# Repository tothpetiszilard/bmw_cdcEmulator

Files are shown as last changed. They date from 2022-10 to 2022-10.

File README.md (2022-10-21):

BMW (E46 and E39) CDC (cd changer) emulator project

- Emulates a CD changer node on the IBUS network
- Controls and reads status of KRC 86B V4.0 bluetooth module (onboard)
- Controls a dfPlayer mini USB and microSD card music player module (onboard)
- Receives multifuction steering wheel commands
- Receives commands and status from the original radio
- Supports some configuration options which can be set using the original radio interface

HW design done in EAGLE
SW is done in MPLABX using its MCC code generator

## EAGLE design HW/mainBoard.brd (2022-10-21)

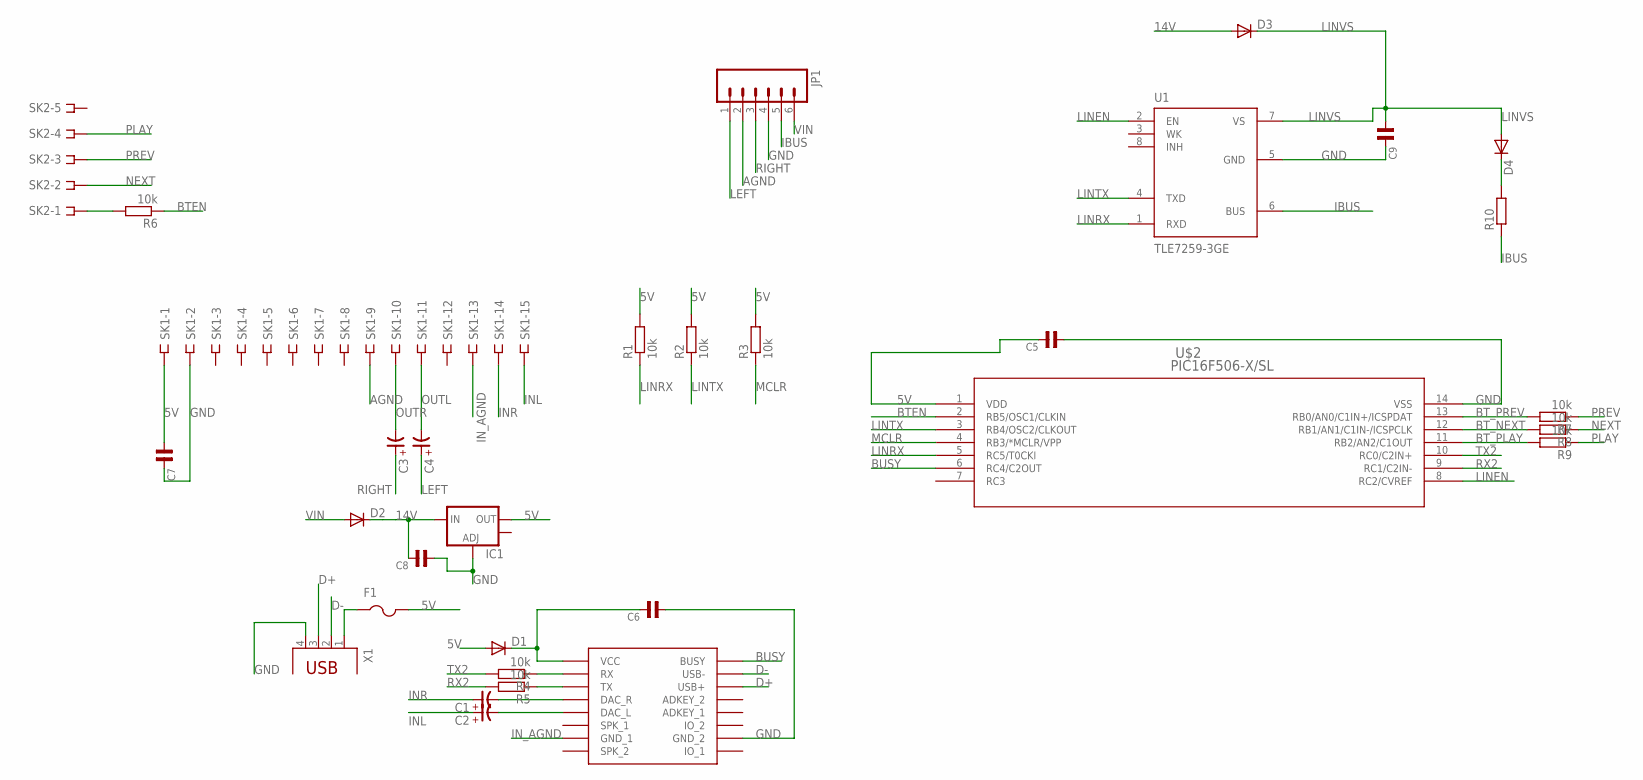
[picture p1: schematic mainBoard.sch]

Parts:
C1, C2, C3, C4: CP-3258-TE-B; 3528-TE-B
C5, C6, C7, C9: C0603; 0603
C8: C1206; 1206
D1, D2: DIODESMA-ALT; SMA-DIODE_ALT
D3, D4: DIODE-SOD80C; SOD80C
F1: PTCFUSE-1812; 1812
IC1: V_REG_LM1117SOT223; SOT223
JP1: M06LONGPADS; 1X06_LONGPADS
R1, R2, R3, R4, R5, R6, R7, R8, R9: 10k; R0603
R10: R-EU_R0603; R0603
SK1: DF3-15S; DF3S-15
SK2: DF3-05S; DF3S-05
U1: TLE7259-3GE; SOIC127P600X175-8N-3
U$1: DFPLAYER
U$2: PIC16F506-X/SL; SOIC14-N_MC
X1: PN87520

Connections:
5V: C5.2, C7.1, D1.A, F1.2, IC1.2 (OUT), R1.2, R2.2, R3.2, SK1.1, U$2.1 (VDD)
14V: C8.2, D2.C, D3.A, IC1.3 (IN)
AGND: JP1.2, SK1.9
BTEN: R6.1, U$2.2 (RB5/OSC1/CLKIN)
BT_NEXT: R8.2, U$2.12 (RB1/AN1/C1IN-/ICSPCLK)
BT_PLAY: R9.2, U$2.11 (RB2/AN2/C1OUT)
BT_PREV: R7.2, U$2.13 (RB0/AN0/C1IN+/ICSPDAT)
BUSY: U$1.BUSY, U$2.6 (RC4/C2OUT)
D+: U$1.USB+, X1.3
D-: U$1.USB-, X1.2
GND: C5.1, C6.1, C7.2, C8.1, C9.2, IC1.1 (ADJ), JP1.4, SK1.2, U1.5 (GND), U$1.GND_2, U$2.14 (VSS), X1.4
IBUS: JP1.5, R10.1, U1.6 (BUS)
INL: C2.+, SK1.15
INR: C1.+, SK1.14
IN_AGND: SK1.13, U$1.GND_1
LEFT: C4.+, JP1.1
LINEN: U1.2 (EN), U$2.8 (RC2/CVREF)
LINRX: R1.1, U1.1 (RXD), U$2.5 (RC5/T0CKI)
LINTX: R2.1, U1.4 (TXD), U$2.3 (RB4/OSC2/CLKOUT)
LINVS: C9.1, D3.C, D4.A, U1.7 (VS)
MCLR: R3.1, U$2.4 (RB3/*MCLR/VPP)
unnamed: C2.-, U$1.DAC_L
unnamed: C1.-, U$1.DAC_R
unnamed: C6.2, D1.C, U$1.VCC
unnamed: R4.1, U$1.RX
unnamed: R5.1, U$1.TX
unnamed: F1.1, X1.1
unnamed: D4.C, R10.2
unnamed: R6.2, SK2.1
NEXT: R8.1, SK2.2
OUTL: C4.-, SK1.11
OUTR: C3.-, SK1.10
PLAY: R9.1, SK2.4
PREV: R7.1, SK2.3
RIGHT: C3.+, JP1.3
RX2: R5.2, U$2.9 (RC1/C2IN-)
TX2: R4.2, U$2.10 (RC0/C2IN+)
VIN: D2.A, JP1.6

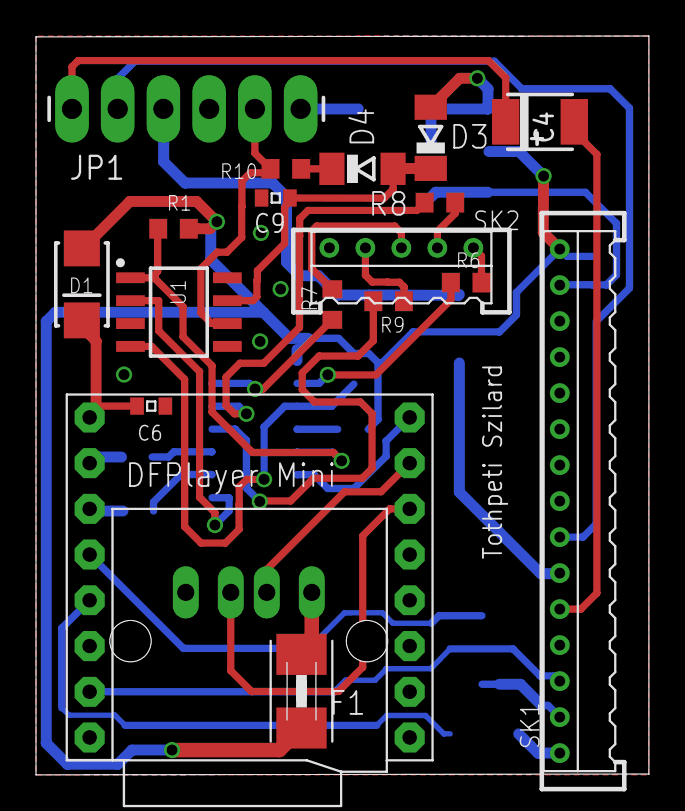
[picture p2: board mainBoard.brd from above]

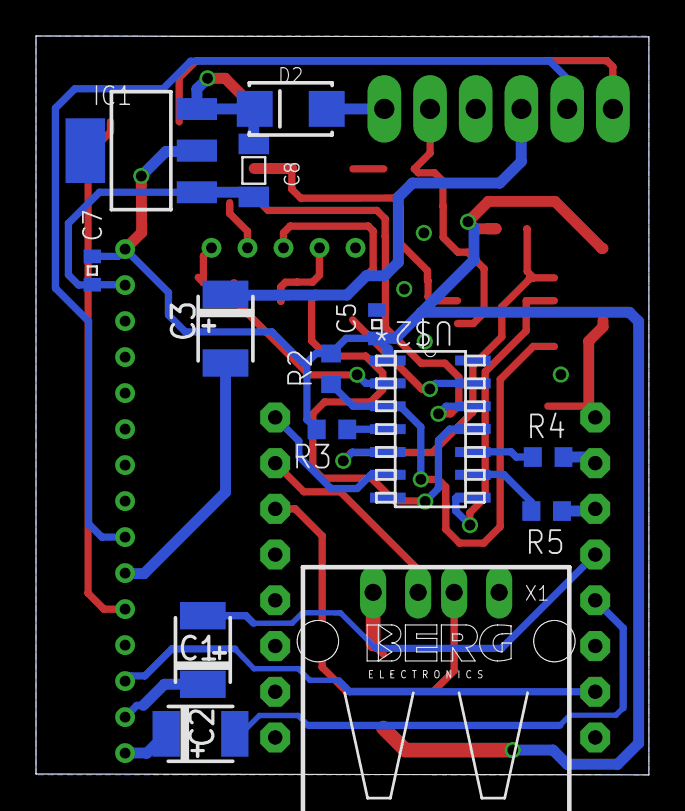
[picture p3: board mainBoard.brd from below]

Board: 2 copper layers, 34.0 x 41.0 mm, 32 parts (14 on the bottom side), 38 nets.

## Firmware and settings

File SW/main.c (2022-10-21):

/**
  Generated Main Source File

  Company:
    Microchip Technology Inc.

  File Name:
    main.c

  Summary:
    This is the main file generated using PIC10 / PIC12 / PIC16 / PIC18 MCUs

  Description:
    This header file provides implementations for driver APIs for all modules selected in the GUI.
    Generation Information :
        Product Revision  :  PIC10 / PIC12 / PIC16 / PIC18 MCUs - 1.65.2
        Device            :  PIC16F18324
        Driver Version    :  2.00
*/

/*
    (c) 2018 Microchip Technology Inc. and its subsidiaries. 
    
    Subject to your compliance with these terms, you may use Microchip software and any 
    derivatives exclusively with Microchip products. It is your responsibility to comply with third party 
    license terms applicable to your use of third party software (including open source software) that 
    may accompany Microchip software.
    
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
    IN NO EVENT WILL MICROCHIP BE LIABLE FOR ANY INDIRECT, SPECIAL, PUNITIVE, 
    INCIDENTAL OR CONSEQUENTIAL LOSS, DAMAGE, COST OR EXPENSE OF ANY KIND 
    WHATSOEVER RELATED TO THE SOFTWARE, HOWEVER CAUSED, EVEN IF MICROCHIP 
    HAS BEEN ADVISED OF THE POSSIBILITY OR THE DAMAGES ARE FORESEEABLE. TO 
    THE FULLEST EXTENT ALLOWED BY LAW, MICROCHIP'S TOTAL LIABILITY ON ALL 
    CLAIMS IN ANY WAY RELATED TO THIS SOFTWARE WILL NOT EXCEED THE AMOUNT 
    OF FEES, IF ANY, THAT YOU HAVE PAID DIRECTLY TO MICROCHIP FOR THIS 
    SOFTWARE.
*/

#include "mcc_generated_files/mcc.h"
#include "BMW_IBUS/IBUS.h"
#include "SysTick/SysTick.h"
#include "BMW_CDC/CDC.h"
/*
                         Main application
 */


void main(void)
{
    // initialize the device
    SYSTEM_Initialize();

    // When using interrupts, you need to set the Global and Peripheral Interrupt Enable bits
    // Use the following macros to:
    // Enable the Global Interrupts
    INTERRUPT_GlobalInterruptEnable();

    // Enable the Peripheral Interrupts
    INTERRUPT_PeripheralInterruptEnable();

    // Disable the Global Interrupts
    //INTERRUPT_GlobalInterruptDisable();

    // Disable the Peripheral Interrupts
    //INTERRUPT_PeripheralInterruptDisable();

    SysTick_Init();
    
    IBUS_Init();

    CDC_Init();    
    while (1)
    {
        // Add your application code
        IBUS_Cyclic();
        CDC_Cyclic();
    }
}
/**
 End of File
*/
    

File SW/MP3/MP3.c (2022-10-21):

#include "MP3.h"
#include "MP3_Cfg.h"

typedef enum _MP3_SrcType_ten
{
    SRC_NOMEDIA = 0u,
    SRC_USB = 1u,
    SRC_SDCARD = 2u
    
}MP3_SrcType_ten;

typedef struct _MP3_ToDoType_tst
{
    uint8_t init_u1 :1;
    uint8_t changeMedia_u1 :1;
    uint8_t getFilesCnt_u1 :1;
    uint8_t start_u1 :1;
    uint8_t pause_u1 :1;
    uint8_t changeTrack_u1 :1;
    uint8_t getTrack_u1 :1;
    uint8_t readNvm_u1 :1;
    uint8_t stop_u1 :1;
}MP3_ToDoType_tst;

static MP3_SrcType_ten currentSrc_en = SRC_NOMEDIA;
static MP3_ToDoType_tst MP3_toDo_st;
static uint8_t MP3_rxBuffer_au8[MP3_RXBUFFER_SIZE];
static uint8_t frameReceived_u8 = 0u;
static uint8_t MP3_txBuffer_au8[MP3_TXBUFFER_SIZE];
static uint16_t currTrack_u16 = 1;
static uint16_t specifiedTrack_u16 = 1u;
static uint16_t maxTrack_u16 = 1;

static uint8_t MP3_MaxTrackInFolder_u8 = 99u;

static void MP3_ProcessFrame(void);
static void MP3_SendCommand(uint8_t cmd_u8, uint8_t para1_u8, uint8_t para2_u8);
static void MP3_Receive(void);
static void MP3_Transmit(void);
static inline void MP3_DecodeRx(void);

void MP3_Init(void)
{
    MP3_UART_INIT();
    frameReceived_u8 = 0u;
    
    MP3_toDo_st.init_u1 = 1u;
    MP3_toDo_st.readNvm_u1 = 1u;
    
}

void MP3_Cyclic(void)
{
    if (0 < frameReceived_u8)
    {
        MP3_ProcessFrame();
    }
    MP3_Receive();
    MP3_Transmit();

}

void MP3_WakeUp(void)
{
   MP3_toDo_st.start_u1 = 1u;
   MP3_toDo_st.getTrack_u1 = 1u;
}

void MP3_SelectTrack(uint8_t folder_u8,uint8_t track_u8)
{
    if (1u < folder_u8)
    {
        specifiedTrack_u16 = ((uint16_t)(folder_u8-1u) * (MP3_MaxTrackInFolder_u8)) + (track_u8);
    }
    else
    {
        specifiedTrack_u16 = (uint16_t)(track_u8);
    }
    
    if (currTrack_u16 != specifiedTrack_u16)
    {
        /* Specify track */
        MP3_toDo_st.changeTrack_u1 = 1u;
    }
    else
    {
        MP3_toDo_st.start_u1 = 1u;
    }
    
}

void MP3_SaveTrack(void)
{
    if (SRC_USB == currentSrc_en)
    {
        MP3_NVM_WRITE(0x1000u | currTrack_u16);
    }
    else
    {
        MP3_NVM_WRITE(currTrack_u16);
    }
}

void MP3_SetMaxTracksPerFolder(uint8_t newValue_u8)
{
    MP3_MaxTrackInFolder_u8 = newValue_u8;
    MP3_NVM_WRITECFG(newValue_u8);
}

uint8_t MP3_GetMaxTracksPerFolder(void)
{
    return MP3_MaxTrackInFolder_u8;
}

void MP3_ChangeMedia(void)
{
    if (SRC_SDCARD == currentSrc_en)
    {
        currentSrc_en = SRC_USB;
    }
    else
    {
        currentSrc_en = SRC_SDCARD;
    }
    MP3_toDo_st.stop_u1 = 1u;
    specifiedTrack_u16 = 1u;
    MP3_toDo_st.changeMedia_u1 = 1u;
}

void MP3_Pause(void)
{
    MP3_toDo_st.pause_u1 = 1u;
}

static void MP3_Transmit(void)
{
    static uint32_t transmitTime_u32 = 1000u;
    uint32_t currTime_u32 = MP3_GETTIME();
    if (transmitTime_u32 < currTime_u32)
    {
        if (MP3_toDo_st.readNvm_u1 == 1u)
        {
            
            currTrack_u16 = MP3_NVM_READ();
            if (0 != (currTrack_u16 & 0x1000u))
            {
                currentSrc_en = SRC_USB;
                MP3_toDo_st.changeMedia_u1 = 1u;
                currTrack_u16 = (currTrack_u16 & 0x0FFFu);
            }
            else
            {
                currentSrc_en = SRC_SDCARD;
                MP3_toDo_st.changeMedia_u1 = 1u;
            }
            specifiedTrack_u16 = currTrack_u16;
            maxTrack_u16 = currTrack_u16;
            MP3_MaxTrackInFolder_u8 = MP3_NVM_READCFG();
            MP3_toDo_st.readNvm_u1 = 0u;
            MP3_toDo_st.getFilesCnt_u1 = 1u;
            MP3_toDo_st.changeTrack_u1 = 1u;
        }
        else if (MP3_toDo_st.init_u1 == 1u)
        {
            MP3_SendCommand(0x16u,0x00u,0x00u); /* Stop command */
            transmitTime_u32 = currTime_u32 + 2000u;
            MP3_toDo_st.init_u1 = 0u;
        }
        else if (MP3_toDo_st.stop_u1 == 1)
        {
            MP3_SendCommand(0x16u,0x00u,0x00u); /* Stop command */
            transmitTime_u32 = currTime_u32 + 200u;
            MP3_toDo_st.stop_u1 = 0u;
        }
        else if (MP3_toDo_st.changeMedia_u1 == 1)
        {
            MP3_SendCommand(0x09u,0x00u,(uint8_t)currentSrc_en); /* Change media */
            transmitTime_u32 = currTime_u32 + 200u;
            MP3_toDo_st.changeMedia_u1 = 0u;
            MP3_toDo_st.getFilesCnt_u1 = 1u;
            MP3_toDo_st.changeTrack_u1 = 1u;
        }
        else if (MP3_toDo_st.getFilesCnt_u1 == 1)
        {
            if (currentSrc_en == SRC_SDCARD)
            {
                MP3_SendCommand(0x48u,0x00u,0x00u); /* Get file count on SD */
            }
            else
            {
                MP3_SendCommand(0x47u,0x00u,0x00u); /* Get file count on SD */
            }
            transmitTime_u32 = currTime_u32 + 200u;
        }
        else if (MP3_toDo_st.changeTrack_u1 == 1)
        {
            MP3_SendCommand(0x03u,MP3_HIGHBYTE(specifiedTrack_u16),MP3_LOWBYTE(specifiedTrack_u16));
            transmitTime_u32 = currTime_u32 + 200u;
            MP3_toDo_st.changeTrack_u1 = 0u;
            MP3_toDo_st.getTrack_u1 = 1u;
        }        
        else if (MP3_toDo_st.getTrack_u1 == 1)
        {
            if (currentSrc_en == SRC_SDCARD)
            {
                MP3_SendCommand(0x4Cu,0x00,0x00); /* Get current track on SD */
            }
            else
            {
                MP3_SendCommand(0x4Bu,0x00,0x00); /* Get current track on USB */
            }
            transmitTime_u32 = currTime_u32 + 200u;
        }
        else if (MP3_toDo_st.start_u1 == 1u)
        {
            MP3_SendCommand(0x0Du,0x00u,0x00); /* Play command */
            transmitTime_u32 = currTime_u32 + 200u;
            MP3_toDo_st.start_u1 = 0u;
        }
        else if (MP3_toDo_st.pause_u1 == 1u)
        {
            MP3_SendCommand(0x0Eu,0x00u,0x00); /* Pause command */
            transmitTime_u32 = currTime_u32 + 200u;
            MP3_toDo_st.pause_u1 = 0u;
        }
        else
        {
            /* Nothing to do, sleep */
        }
    }
}

static void MP3_SendCommand(uint8_t cmd_u8, uint8_t para1_u8, uint8_t para2_u8)
{
    uint8_t tmp_u8 = 0u;
    uint16_t checksum_u16 =0u;
    MP3_txBuffer_au8[0u] = MP3_STARTBYTE_U8;
    MP3_txBuffer_au8[1u] = MP3_VERSION_U8;
    MP3_txBuffer_au8[2u] = 6u;
    MP3_txBuffer_au8[3u] = cmd_u8;
    MP3_txBuffer_au8[4u] = 1u; /* No feedback needed */
    MP3_txBuffer_au8[5u] = para1_u8;
    MP3_txBuffer_au8[6u] = para2_u8;
    MP3_txBuffer_au8[9u] = MP3_ENDBYTE_u8;
    for (tmp_u8 = 0; tmp_u8 < 6u; tmp_u8++)
    {
        checksum_u16 -= (uint16_t)MP3_txBuffer_au8[1u+tmp_u8];
    }
    MP3_txBuffer_au8[7] = MP3_HIGHBYTE(checksum_u16);
    MP3_txBuffer_au8[8] = MP3_LOWBYTE(checksum_u16);
    for (tmp_u8 = 0; tmp_u8 < MP3_TXBUFFER_SIZE; tmp_u8++)
    {
        MP3_UART_WRITE(MP3_txBuffer_au8[tmp_u8]);
    }
}
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

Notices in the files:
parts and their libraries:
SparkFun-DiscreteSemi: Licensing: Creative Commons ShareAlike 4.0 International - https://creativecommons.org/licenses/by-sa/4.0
